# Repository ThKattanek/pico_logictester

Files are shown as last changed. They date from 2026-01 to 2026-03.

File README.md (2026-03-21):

# 🔌 Pico Logic Tester

  

> **Ein portabler 16-Kanal Logic Tester basierend auf dem Raspberry Pi Pico**

Der Pico Logic Tester ist ein handliches Debugging-Tool für Hardware-Entwickler. Er ersetzt die klassischen Test-LEDs und zeigt bis zu 16 digitale Signale gleichzeitig in Echtzeit auf einem farbigen TFT-Display an.

<div style="text-align: left; margin-left: 0; padding-left: 0;">
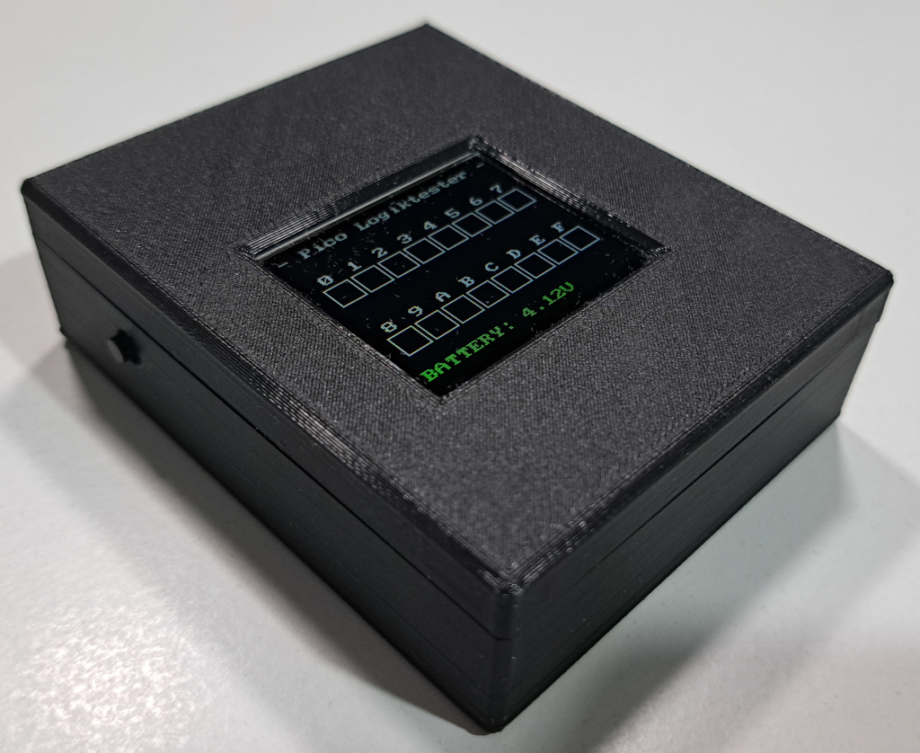
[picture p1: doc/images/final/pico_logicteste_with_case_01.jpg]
  
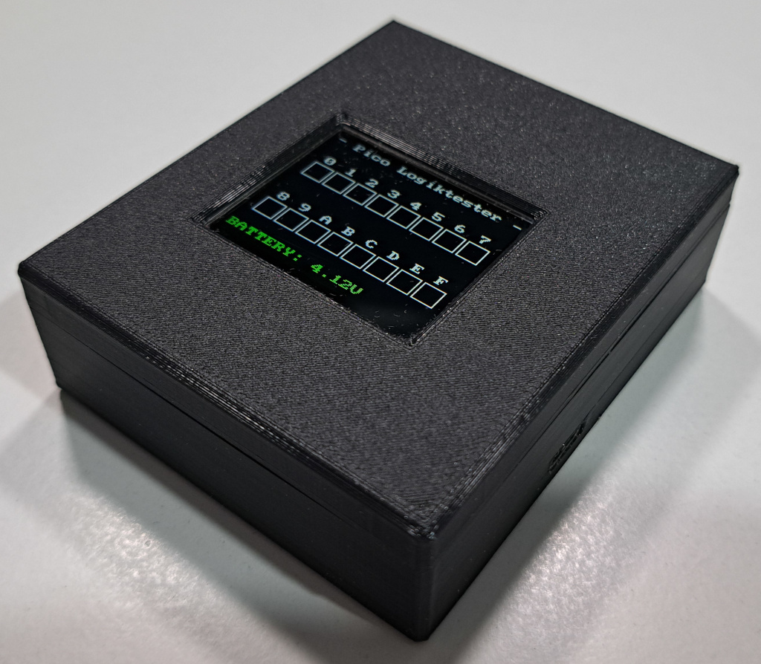
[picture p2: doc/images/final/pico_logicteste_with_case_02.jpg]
  
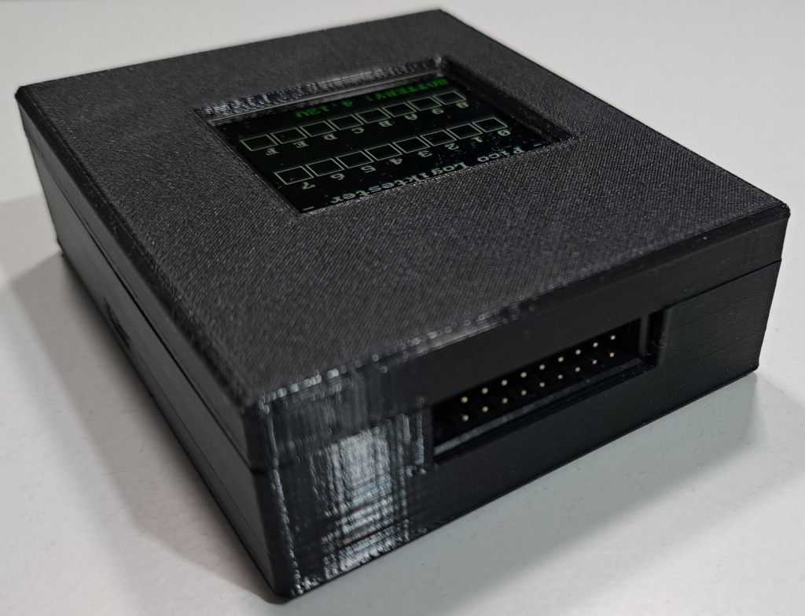
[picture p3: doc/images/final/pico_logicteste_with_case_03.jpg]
  
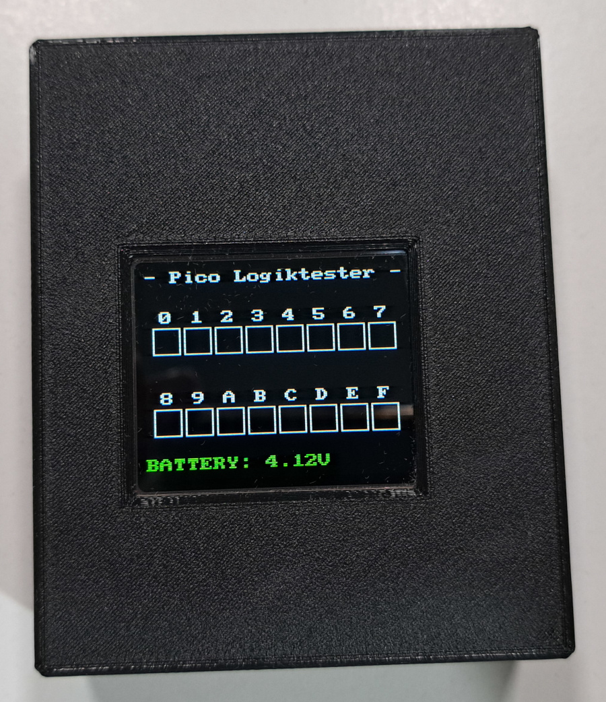
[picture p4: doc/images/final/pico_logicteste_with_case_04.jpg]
  
</div>

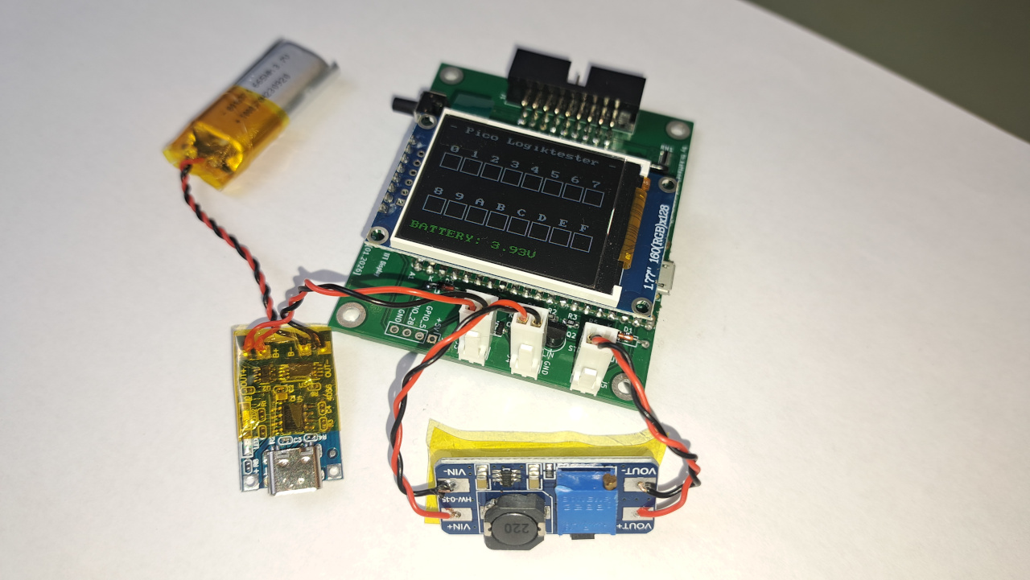
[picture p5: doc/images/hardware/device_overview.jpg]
Pico Logic Tester Overview

*Der Pico Logic Tester in Aktion*

---

## Key Features

| Feature | Beschreibung |
|---|---|
| **16 Logic Inputs** | GPIO 6-17, 20-22, 26-27 |
| **1,77" TFT Display** | 128x160 Pixel, 16-bit Farbe |
| **Akku-betrieben** | Li-Ion mit USB-C Laden |
| **3.3V & 5V tolerant** | Sichere Eingangsstufe |
| **Echtzeit-Anzeige** | <10ms Reaktionszeit |
| **Open Source** | Hardware & Software frei verfügbar |

---

## 🛠️ Technische Daten

### Hardware Specs
| Komponente | Spezifikation |
|---|---|
| **MCU** | Raspberry Pi Pico (RP2040/RP2350) |
| **Display** | ST7735S, 128×160, SPI |
| **Eingänge** | 16× Digital, 0-5V |
| **Stromversorgung** | 3.7V Li-Ion Akku |
| **Gehäuse** | 120×80×25mm (3D-druckbar) |
| **Gewicht** | ~150g |

### Performance
- **Scan-Rate:** 200Hz (5ms pro Zyklus)
- **Logic Levels:** LOW <0.8V, HIGH >2.5V 
- **Akkulaufzeit:** ~8-12 Stunden aktiv
- **Display-Update:** Nur bei Änderungen (optimiert)

---

## 🚀 Quick Start

### 1. Hardware Setup
```
1. Akku über USB-C laden (grüne LED = voll)
2. Logic Tester einschalten (kurzer Power-Button Druck)
3. GND-Referenz mit Testobjekt verbinden
4. Testleitungen an Eingänge 0-15 anschließen
```

### 2. Display Interpretation
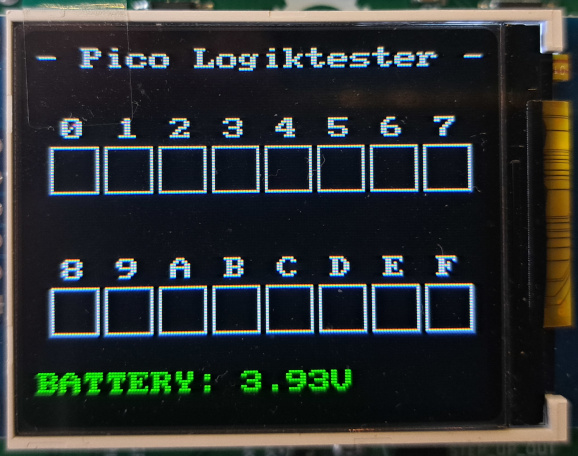
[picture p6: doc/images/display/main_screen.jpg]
Display Layout


| Anzeige | Bedeutung |
|---|---|
| **Grüne Box** | Logic HIGH (>2.5V) |
| **Schwarze Box** | Logic LOW (<0.8V) |
| **Grün/Gelb/Rot** | Batteriestatus |

### 3. Ein/Ausschalten
- **EIN:** Kurzer Tastendruck (<1s)
- **AUS:** Langer Tastendruck (>2s)
- **Auto-OFF:** Bei kritischem Batteriestand

---

## 📁 Repository Struktur

```
pico_logictester/
├── README.md                    # Diese Datei
├── LICENSE                      # GPL v2 Lizenz
├── firmware/                    # Pico C++ Firmware
│   ├── src/main.cpp               # Hauptprogramm
│   ├── CMakeLists.txt             # Build Config
│   └── include/displaylib_16/     # Display Treiber
├── hardware/                    # KiCad PCB Design
│   ├── pico_logictester.kicad_*   # Schaltplan & Layout
│   ├── gerber/                    # Produktionsdaten
│   └── bom/                       # Interaktive Stückliste
└── doc/                         # Dokumentation
    ├── pico_logictester_dokumentation.md  # Vollständige Doku
    ├── pico_logictester_dokumentation.pdf # PDF Version
    └── images/                     # Bilder & Diagramme
```

---

## 🔨 Build & Flash

### Voraussetzungen
- **Pico SDK** (v2.2.0+)
- **CMake** (v3.13+) 
- **ARM GCC Toolchain**

### Kompilierung
```bash
cd firmware
mkdir build && cd build
cmake ..
make -j4
```

### Programmierung
```bash
# UF2 auf Pico kopieren (BOOTSEL Mode)
cp pico_logictester.uf2 /media/<user>/RPI-RP2/

# Oder mit picotool
picotool load pico_logictester.uf2
```

---

## 📸 Screenshots

<table>
<tr>
<td align="center">
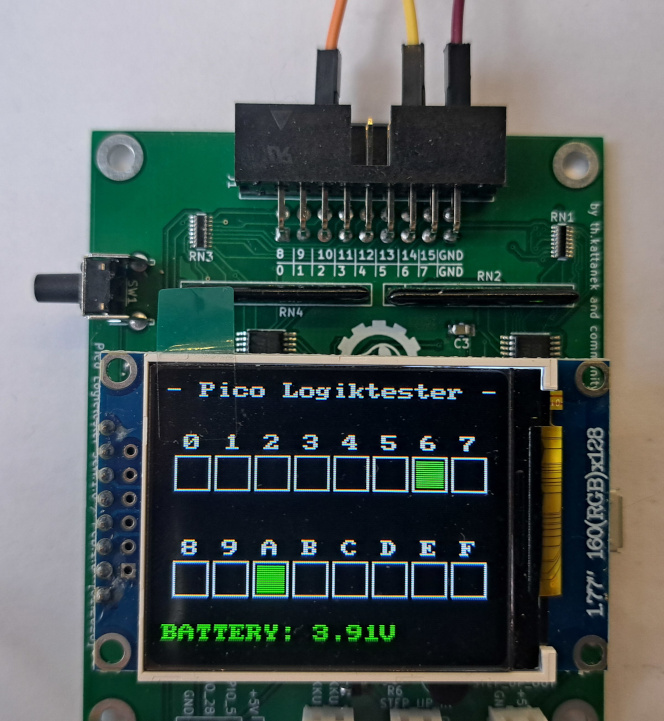
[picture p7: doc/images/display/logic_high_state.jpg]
<br>
<b>Logic HIGH Signale</b>
</td>
<td align="center">
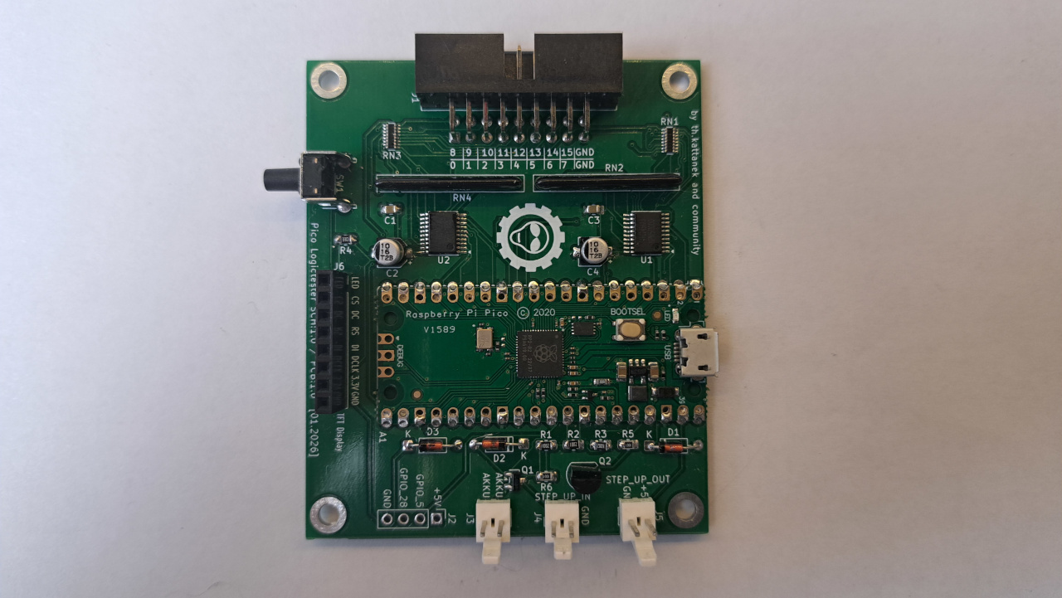
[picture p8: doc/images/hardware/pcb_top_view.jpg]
<br>
<b>PCB Design</b>
</td>
</tr>
</table>

---

## 📚 Dokumentation

| Dokument | Beschreibung | Format |
|---|---|---|
| 📋 **[Vollständige Dokumentation](doc/pico_logictester_dokumentation.md)** | Detaillierte Hardware/Software Beschreibung | Markdown |
| 📄 **[PDF Version](doc/pico_logictester_dokumentation.pdf)** | Druckbare Dokumentation | PDF |
| 🔧 **[Hardware BOM](hardware/bom/pico_logictester_pcb_1.0_ibom.html)** | Interaktive Stückliste | HTML |

### Was Sie in der Dokumentation finden:
- **Hardware-Design:** Schaltplan, PCB-Layout, Stückliste
- **Software-Architektur:** C++ Code-Struktur, Performance-Optimierungen  
- **Benutzerhandbuch:** Bedienung, Fehlerbehebung, Kalibrierung
- **Fertigung:** PCB-Produktion, 3D-Druck Gehäuse
- **Entwicklung:** Build-System, Debugging, Erweiterungen

---

## Beitragen

Contributions sind willkommen!

### Wie Sie helfen können:
- **Bug Reports:** Issues über GitHub melden
- **Feature Requests:** Neue Ideen vorschlagen  
- **Code:** Pull Requests für Verbesserungen
- **Dokumentation:** Rechtschreibfehler, Übersetzungen
- **Testing:** Hardware-Tests, Kompatibilitätsprüfung

### Development Workflow:
```bash
1. Fork das Repository
2. Feature Branch erstellen (`git checkout -b feature/amazing-feature`)
3. Änderungen committen (`git commit -m 'Add amazing feature'`)
4. Branch pushen (`git push origin feature/amazing-feature`)
5. Pull Request öffnen
```

---

## 📜 Lizenz

Dieses Projekt steht unter der **GNU General Public License v2.0**.

- ✅ **Kommerzieller Einsatz erlaubt**
- ✅ **Modifikation erlaubt** 
- ✅ **Distribution erlaubt**
- ❗ **Quellcode muss verfügbar sein**
- ❗ **Gleiche Lizenz für Ableitungen**

Siehe [LICENSE](LICENSE) für Details.

---

## Show your Support

Wenn Ihnen dieses Projekt gefällt:
- **Star** das Repository
- **Fork** für eigene Experimente  
- **Teilen** mit anderen Hardware-Hackern
- **Feedback** über Issues

---

## 📞 Kontakt & Support

| Kanal | Link | Beschreibung |
|---|---|---|
| 👤 **Autor** | Thorsten Kattanek | Hardware & Software Development |
| 📧 **E-Mail** | thorsten@kattanek.de | Direkte Fragen & Support |
| 🐙 **GitHub** | [ThKattanek/pico_logictester](https://github.com/ThKattanek/pico_logictester) | Source Code & Issues |
| 🐛 **Bug Reports** | [GitHub Issues](https://github.com/ThKattanek/pico_logictester/issues) | Bugs & Feature Requests |

---

<div align="center">

**Made with ❤️ for Hardware Debugging**

*Happy Coding!*

</div>

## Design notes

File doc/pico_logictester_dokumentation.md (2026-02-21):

# Pico Logic Tester - Projektdokumentation

**Version:** 1.0  
**Datum:**   21. Februar 2026  
**Autor:**   Thorsten Kattanek  

---

## 1. Projektübersicht

### 1.1 Beschreibung
Der Pico Logic Tester ist ein tragbares Messgerät zur Überwachung digitaler Signale, basierend auf dem Raspberry Pi Pico Mikrocontroller. Das Gerät kann bis zu 16 Logikeingänge gleichzeitig überwachen und den Zustand (HIGH/LOW) in Echtzeit auf einem farbigen TFT-Display anzeigen. Die Eingänge sind 3.3V und 5V Tolerant. Es ersetzt kein Logic Analyzer, vielmehr die LED's zum Debuggen von Hardware Schaltungen.

### 1.2 Hauptmerkmale
- **16 Logikeingänge** (GPIO 6-17, 20-22, 26-27)
- **1,77" ST7735 TFT-Display** (128x160 Pixel)
- **Batterieüberwachung** mit Spannungsanzeige
- **Power-Management** mit Ein-/Ausschaltfunktion
- **Portable Bauweise** mit integrierter Stromversorgung
- **Echtzeit-Anzeige** mit optimierter Performance

### 1.3 Technische Spezifikationen
- **Mikrocontroller:** Raspberry Pi Pico (RP2040) oder Pico2 (RP2350)
- **Betriebsspannung:** 3,3V - 4,2V (Li-Ion Akku)
- **Eingangsspannung:** 0V - 5V (tolerant)
- **Display:** ST7735S, 128x160 Pixel, 16-bit Farbtiefe
- **Kommunikation:** SPI (Display), GPIO (Logikeingänge)
- **Stromverbrauch:** ~50mA (aktiv), <1µA (Standby)

---

## 2. Hardware-Design

Gesamtansicht des Pico Logictester
*Abbildung 1: Gesamtansicht des Pico Logictester "noch" ohne Gehäuse*

### 2.1 Schaltungsaufbau
Die Hardware basiert auf einem zweischichtigen PCB-Design mit folgenden Hauptkomponenten:

PCB Oberseite
*Abbildung 2: PCB Oberseite mit bestückten Komponenten*

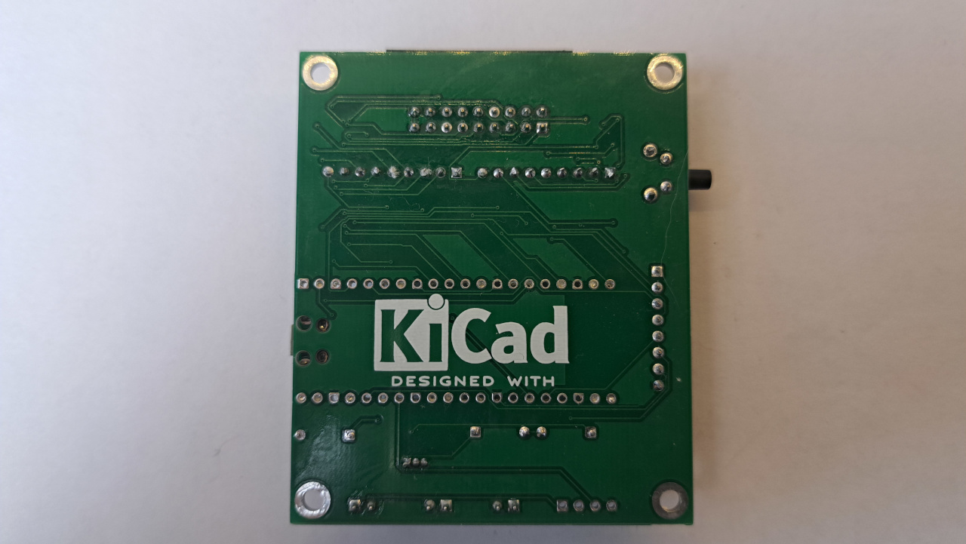
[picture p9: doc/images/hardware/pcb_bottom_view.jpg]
PCB Unterseite

*Abbildung 3: PCB Unterseite mit Leiterbahnen*

#### 2.1.1 Mikrocontroller-Sektion
- **RP2040 oder RP2350** als zentrale Verarbeitungseinheit (auf dem Pico1 oder Pico2 Board)
- **Externe Oszillatorbeschaltung** für stabile Taktversorgung (auf dem Pico1 oder 2 Board)
- **Keine Übertaktung** für einen sicheren und stabilen Betrieb
- **Power-Management-Schaltung** mit PNP-Transistor und MOSFET
- **Das Raspberry Pi Pico Board** wird direkt auf die Platine gelötet

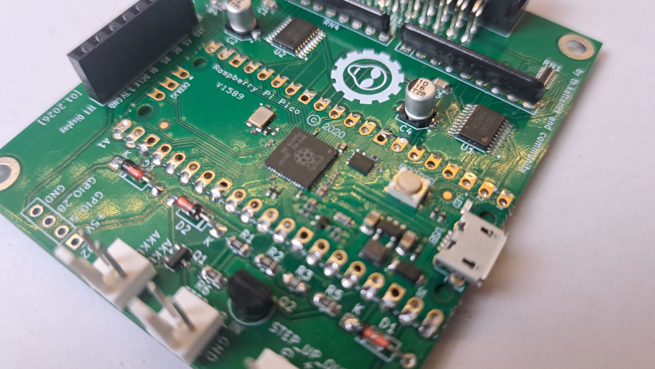
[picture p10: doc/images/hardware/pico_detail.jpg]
Pico Mikrocontroller Detail

*Abbildung 4: Detailansicht der Pico-Mikrocontroller Sektion*

#### 2.1.2 Eingangsstufe
- **16 Logikeingänge** mit Schutzwiderständen
- **74HC245** als schneller und zuverlässiger Pegelwandler
- **Pull-Down Widerstände** für definierte Pegel

#### 2.1.3 Display-Interface
- **ST7735S TFT-Controller** über SPI-Interface
- **Dedicated GPIO-Pins** für CS, DC, RST, SDIN und SDCLCK

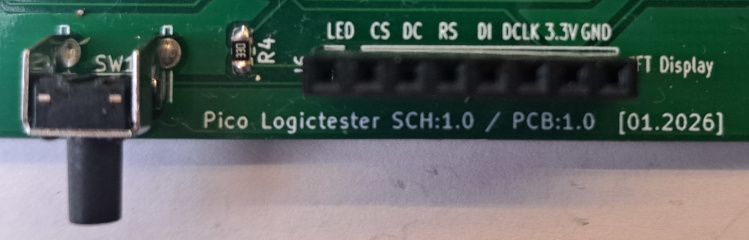
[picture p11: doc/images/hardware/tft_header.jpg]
Pinout TFT Header

*Abbildung 5: Pin Belegung des TFT Anschluss*

#### 2.1.4 Stromversorgung
- **Li-Ion Akkuanschluss** (3,7V nominal)
- **Laderegler-Modul (18650 Lithium Battery Charger)** mit USB-C Anschluss
- **StepUp Wandler Modul MT3608** erzeugt Stabile 5V für das ganze System
- **Spannungsüberwachung** über ADC-Eingang
- **Power-Switch mit Latching** über Taster

### 2.2 Pin-Belegung

#### 2.2.1 Display-Pins (SPI0)
```
TFT_CS_PIN    = GPIO 2   (Chip Select)
TFT_DC_PIN    = GPIO 3   (Data/Command)
TFT_RST_PIN   = GPIO 4   (Reset)
TFT_SDIN_PIN  = GPIO 19  (MOSI)
TFT_SCLK_PIN  = GPIO 18  (Serial Clock)
```

#### 2.2.2 Power-Management
```
SYSTEM_POWER_PIN = GPIO 0  (Power Control)
POWER_BUTTON_PIN = GPIO 1  (Power Button Input)
BATTERY_ADC_PIN  = GPIO 27 (Battery Voltage Monitoring)
```

#### 2.2.3 Debug-Interface
```
DEBUG_LED_PIN = GPIO 25   (Onboard LED für Status-Anzeige)
```

#### 2.2.3 Logikeingänge
```
LOGIC_PIN_0  = GPIO 6    LOGIC_PIN_8  = GPIO 14
LOGIC_PIN_1  = GPIO 7    LOGIC_PIN_9  = GPIO 15
LOGIC_PIN_2  = GPIO 8    LOGIC_PIN_10 = GPIO 16
LOGIC_PIN_3  = GPIO 9    LOGIC_PIN_11 = GPIO 17
LOGIC_PIN_4  = GPIO 10   LOGIC_PIN_12 = GPIO 20
LOGIC_PIN_5  = GPIO 11   LOGIC_PIN_13 = GPIO 21
LOGIC_PIN_6  = GPIO 12   LOGIC_PIN_14 = GPIO 22
LOGIC_PIN_7  = GPIO 13   LOGIC_PIN_15 = GPIO 26
```

---

## 3. Software-Architektur

### 3.1 Systemarchitektur
Die Firmware ist in C++ geschrieben und verwendet das Pico SDK. Die Software folgt einer ereignisgesteuerten Architektur mit optimierter Performance für Echtzeit-Anwendungen.

### 3.2 Hauptkomponenten

#### 3.2.1 Power Management System
```cpp
// Funktionen:
- InitPowerManagement()      // Initialisierung der Power-Kontrolle
- CheckPowerButton()         // Überwachung des Power-Buttons
- PowerOff()                 // Sicheres Herunterfahren
```

**Features:**
- Interrupt-gesteuerte Tastererkennung
- 2-Sekunden-Timeout für sicheres Ausschalten
- Automatische Abschaltung bei kritischer Batteriespannung

#### 3.2.2 Battery Monitoring System
```cpp
// Funktionen:
- InitBatteryMonitoring()    // ADC-Initialisierung
- ReadBatteryVoltage()       // Spannungsmessung
- UpdateBatteryMovingAverage() // Gleitender Mittelwert
- DisplayBatteryStatus()     // Anzeige der Batteriespannung
```

**Features:**
- 12-bit ADC mit 3,3V Referenz
- 50-Werte gleitender Mittelwert für stabile Messung
- Farbkodierte Warnanzeige (Grün/Gelb/Rot)
- Automatische Abschaltung bei <3,5V

#### 3.2.3 Logic Input System
```cpp
// Funktionen:
- InitLogicPinsAsInput()     // GPIO-Initialisierung
- ReadAllLogicPins()         // Bulk-GPIO-Read
- UpdateLogicDisplay()       // Selektive Display-Updates
```

**Features:**
- Optimierte Bulk-GPIO-Operationen
- Änderungsbasierte Display-Updates
- Sub-10ms Reaktionszeit
- 16MHz SPI für flüssige Anzeige

#### 3.2.4 Display System
Das Display-System basiert auf der `displaylib_16` Bibliothek mit ST7735-Treiber.

**Features:**
- Hardware-SPI mit 16MHz Taktrate
- 16-bit Farbtiefte (65.536 Farben)
- Optimierte Zeichenfunktionen
- Rotationsunterstützung (0°, 90°, 180°, 270°)

#### 3.2.5 Debug-System
```cpp
// Debug-LED Funktionen:
- LED_PIN = GPIO 25          // Onboard-LED des Pico
- gpio_put(LED_PIN, 1)       // LED einschalten bei Startup
- Visueller Indikator für Systemstart
- Debugging-Unterstützung bei Entwicklung
```

**Features:**
- Automatisches LED-Signal beim Systemstart
- Status-Anzeige für Hardware-Debugging
- Einfache Erweiterung für weitere Debug-Signale

### 3.3 Performance-Optimierungen

#### 3.3.1 Echzeit-Verhalten
- **Hauptschleife:** 5ms Zykluszeit
- **GPIO-Read:** Bulk-Operation in <1µs
- **Display-Update:** Nur bei Änderungen
- **Batteriemessung:** 100ms Intervall

#### 3.3.2 Memory Management
- **Stack-optimierte Variablen**
- **Konstante Arrays im Flash**
- **Minimale Heap-Nutzung**
- **Optimierte Puffergröße**

---

## 4. Benutzerhandbuch

### 4.1 Inbetriebnahme

#### 4.1.1 Erste Verwendung
1. **Akku laden:** USB-C Kabel anschließen bis LED grün leuchtet
2. **Einschalten:** Power-Taste kurz drücken
3. **Display-Check:** Anzeige sollte "Pico Logiktester" zeigen
4. **Funktionstest:** Testspannungen an Eingänge anlegen

#### 4.1.2 Bedienung
- **Einschalten:** Kurzer Tastendruck (<1s)
- **Ausschalten:** Langer Tastendruck (>2s)
- **Automatische Abschaltung:** Bei kritischer Batteriespannung

### 4.2 Display-Anzeige

Hauptbildschirm
*Abbildung 6: Hauptbildschirm mit allen 16 Logikeingängen*

#### 4.2.1 Bildschirmaufteilung
```
+---------------------------+
|   - Pico Logiktester -    |  <- Header
+---------------------------+
|  0  1  2  3  4  5  6  7   |  <- Eingänge 0-7
| [_][_][_][_][_][_][_][_]  |
|                           |
|  8  9  A  B  C  D  E  F   |  <- Eingänge 8-15 (hex)
| [_][_][_][_][_][_][_][_]  |
+---------------------------+
| BATTERY: 4.05V            |  <- Batterie Anzeige
+---------------------------+
```

#### 4.2.2 Statusanzeige
- **Grüne Box:** Logik HIGH (>2,5V)
- **Schwarze Box:** Logik LOW (<0,8V)
- **Batterieanzeige:**
  - Grün: >3,7V (gut)
  - Gelb: 3,5V-3,7V (niedrig)
  - Rot: <3,5V (kritisch) (system wird automatisch runter gefahren)

Logic HIGH Anzeige
*Abbildung 7: Display mit mehreren HIGH-Signalen (grüne Boxen)*

### 4.3 Messverfahren

#### 4.3.1 Digitale Signale
- **Eingangsspannung:** 0V - 5V
- **Schaltschwellen:**
  - LOW: <0,8V
  - HIGH: >2,5V
- **Maximale Frequenz:** ~50Hz (begrenzt durch Display)

#### 4.3.2 Anschluss
1. **GND-Verbindung** zwischen Testobjekt und Logic Tester herstellen
2. **Messleitungen** an zu überwachende Signale anschließen  
3. **Eingangsnummer beachten** (0-15, entspricht GPIO-Mapping)

---

## 5. Entwicklung und Build

### 5.1 Build-System

#### 5.1.1 Voraussetzungen
```bash
# Pico SDK Installation
sudo apt install cmake gcc-arm-none-eabi libnewlib-arm-none-eabi \
                 build-essential libstdc++-arm-none-eabi-newlib

# Pico SDK (Version 2.2.0)
git clone https://github.com/raspberrypi/pico-sdk.git
export PICO_SDK_PATH=/path/to/pico-sdk
```

#### 5.1.2 Kompilierung
```bash
cd firmware
mkdir build && cd build
cmake ..
make -j4
```

#### 5.1.3 Programmierung
```bash
# UF2-Datei auf Pico kopieren (Bootsel-Modus)
cp pico_logictester.uf2 /media/<user>/RPI-RP2/

# Oder mit picotool
picotool load pico_logictester.uf2
```

### 5.2 Entwicklungsumgebung

#### 5.2.1 Empfohlene IDE
- **VS Code** mit Pico Extension

#### 5.2.2 Debugging
```bash
# SWD-Debugging mit Pico Debug Probe
openocd -f interface/cmsis-dap.cfg -f target/rp2040.cfg
arm-none-eabi-gdb build/pico_logictester.elf
```

### 5.3 Code-Struktur

#### 5.3.1 Verzeichnisstruktur
```
firmware/
├── CMakeLists.txt
├── src/
│   ├── main.cpp                 # Hauptprogramm
│   └── displaylib_16/           # Display-Bibliothek
│       ├── st7735.cpp           # ST7735 Treiber
│       ├── displaylib_16_*.cpp  # Grafik-Funktionen
│       └── ...
├── include/
│   └── displaylib_16/           # Header-Dateien
└── build/                       # Build-Artefakte
```

#### 5.3.2 Abhängigkeiten
```cmake
# CMakeLists.txt Ziele
target_link_libraries(pico_logictester
    pico_displaylib_16    # Eigene Display-Bibliothek
    hardware_spi          # SPI-Hardware
    hardware_adc          # ADC-Hardware  
    pico_stdlib           # Pico Standard-Bibliothek
)
```

---

## 6. Hardware-Fertigung

### 6.1 PCB-Spezifikationen

#### 6.1.1 Platinen-Parameter
- **Schichtanzahl:** 2 Layer
- **Platinen-Dicke:** 1,6mm
- **Kupfer-Dicke:** 35µm (1oz)
- **Via-Größe:** min 0,3mm Bohrdurchmesser
- **Leiterbahnbreite:** min. 0,2mm
- **Oberflächenfinish:** Bleifreies HASL

#### 6.1.2 Bestückung
- **SMD-Komponenten:** 0805 und 1206
- **Durchkontaktierte Bauteile:** THT-Stecker
- **Kritische Toleranzen:** ±5% (Widerstände), ±10% (Kondensatoren)

### 6.2 Stückliste (BOM)

Siehe unter hardware/bom, dort gibt es eine Interaktive Stückliste als HTML File. 

### 6.3 Gehäuse

#### 6.3.1 Mechanische Abmessungen
- **Außenmaße:** 120mm x 80mm x 25mm
- **Display-Ausschnitt:** 30mm x 26mm
- **Taster-Bohrung:** Ø6mm
- **Anschluss-Raster:** 2,54mm (16-pol Stiftleiste)

#### 6.3.2 Material-Empfehlungen
- **Gehäuse:** ABS oder PETG (3D-Druck)
- **Display-Schutz:** Acrylglas 2mm
- **Dichtungen:** Silikonprofil für IP54

---

## 7. Fehlerbehebung

### 7.1 Häufige Probleme

#### 7.1.1 Display bleibt schwarz
**Symptome:** Kein Bild nach dem Einschalten
**Ursachen:**
- Unterbrochene SPI-Verbindung
- Defekte Display-Spannungsversorgung
- Falsche Display-Initialisierung

**Lösungsansätze:**
```cpp
// Debug-Code für Display-Test
tft_display.fillScreen(ST7735_TFT::C_RED);  // Test mit rotem Bildschirm
```

#### 7.1.2 Eingänge reagieren nicht
**Symptome:** Keine Änderung der Logic-Anzeige
**Ursachen:**
- GPIO-Pins nicht korrekt initialisiert
- Hardwarefehler auf Eingangsstufe
- Software-Bug in ReadAllLogicPins()

**Lösungsansätze:**
```cpp
// Debug einzelner GPIO-Pin
printf("GPIO %d: %d\n", LOGIC_PIN_0, gpio_get(LOGIC_PIN_0));
```

#### 7.1.3 Batterie-Anzeige falsch
**Symptome:** Unrealistische Spannungswerte
**Ursachen:**
- ADC-Referenzspannung falsch
- Spannungsteiler-Verhältnis inkorrekt
- Schlechte ADC-Kalibrierung

**Lösungsansätze:**
```cpp
// ADC-Rohwerte prüfen
uint16_t raw = adc_read();
printf("ADC raw: %d\n", raw);
```

### 7.2 Debug-Ausgaben

#### 7.2.1 UART-Debugging
```cpp
// main.cpp - Debug-Ausgaben aktivieren
stdio_init_all();
pico_enable_stdio_uart(${PROJECT_NAME} 1);

// Verwenden in Code:
printf("Battery: %.2fV, Logic: 0x%04X\n", battery_voltage, logic_state);
```

#### 7.2.2 LED-Signaling
```cpp
// Status-LED für Fehlerdiagnose (bereits implementiert)
#define DEBUG_LED_PIN 25  // Onboard-LED des Pico
gpio_init(DEBUG_LED_PIN);
gpio_set_dir(DEBUG_LED_PIN, GPIO_OUT);
gpio_put(DEBUG_LED_PIN, 1); // LED an bei Startup

// Erweiterte Fehlercodes durch Blink-Sequenzen
void blink_error_code(int error_code) {
    for(int i = 0; i < error_code; i++) {
        gpio_put(DEBUG_LED_PIN, 1);
        sleep_ms(200);
        gpio_put(DEBUG_LED_PIN, 0);
        sleep_ms(200);
    }
}

// Status-Signale:
// - Dauerhaft AN: System erfolgreich gestartet
// - Blink-Codes: Verschiedene Fehlerzustände
```

---

## 8. Wartung und Pflege

### 8.1 Routinewartung

#### 8.1.1 Batteriepflege
- **Ladezyklen:** Nicht vollständig entladen lassen
- **Lagerung:** Bei 50% SOC lagern wenn unbenutzt
- **Lade-Temperatur:** 10°C - 45°C optimal
- **Austausch:** Nach ca. 500 Ladezyklen

#### 8.1.2 Reinigung
- **Display:** Mit Mikrofasertuch trocken reinigen
- **Gehäuse:** Mit feuchtem Tuch (destilliertes Wasser)
- **Anschlüsse:** Mit Kontaktspray behandeln
- **Lagerung:** In antistatischer Hülle

### 8.2 Kalibrierung

#### 8.2.1 Batteriespannung
```cpp
// Kalibrierung der ADC-Messung
const float ADC_CALIBRATION_FACTOR = 1.02f;  // Anpassung nach Messung
float voltage = adc_raw * ADC_CONVERSION_FACTOR * 
                VOLTAGE_DIVIDER_FACTOR * ADC_CALIBRATION_FACTOR;
```

#### 8.2.2 Eingangsschwellen
```cpp
// Logic-Level Kalibrierung  
const float LOGIC_LOW_THRESHOLD = 0.8f;   // Anpassbar
const float LOGIC_HIGH_THRESHOLD = 2.5f;  // Anpassbar
```

---

## 9. Anhang

### 9.1 Technische Referenzen

#### 9.1.1 Datenblätter
- [RP2040 Datasheet](https://datasheets.raspberrypi.org/rp2040/rp2040-datasheet.pdf)
- [ST7735 Controller](https://www.adafruit.com/datasheets/ST7735R_V0.2.pdf)
- [Pico SDK Documentation](https://raspberrypi.github.io/pico-sdk-doxygen/)

#### 9.1.2 Application Notes
- **AN001:** Power Management Best Practices
- **AN002:** EMV-Design für portable Geräte  
- **AN003:** Li-Ion Battery Safety

### 9.2 Lizenz und Copyright

#### 9.2.1 Software-Lizenz
```
GNU General Public License Version 2

Copyright (C) 2026 Thorsten Kattanek

This program is free software; you can redistribute it and/or modify
it under the terms of the GNU General Public License as published by
the Free Software Foundation; either version 2 of the License, or
(at your option) any later version.

This program is distributed in the hope that it will be useful,
but WITHOUT ANY WARRANTY; without even the implied warranty of
MERCHANTABILITY or FITNESS FOR A PARTICULAR PURPOSE.  See the
GNU General Public License for more details.

You should have received a copy of the GNU General Public License along
with this program; if not, write to the Free Software Foundation, Inc.,
51 Franklin Street, Fifth Floor, Boston, MA 02110-1301 USA.

Die vollständige Lizenz finden Sie in der Datei LICENSE im Repository.
```

#### 9.2.2 Hardware-Lizenz
Das Hardware-Design steht unter Creative Commons Attribution-ShareAlike 4.0 International License.

**Autor:** Thorsten Kattanek  
**E-Mail:** mail@thorsten-kattanek.de  
**Repository:** https://github.com/ThKattanek/pico_logictester  
**Issues:** Bug-Reports und Feature-Requests über GitHub Issues

---

*Dokumentation erstellt am 21. Februar 2026*  
*Version 1.0*

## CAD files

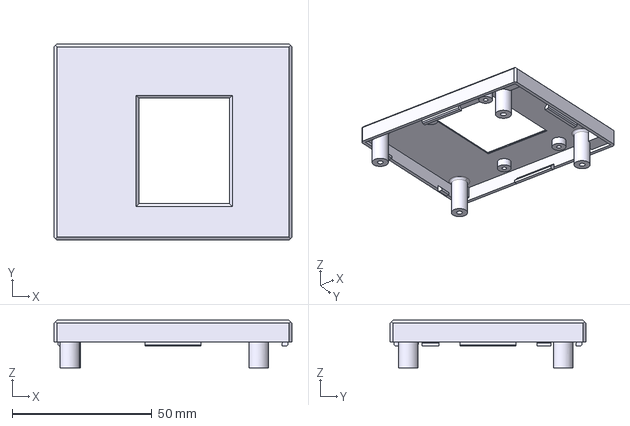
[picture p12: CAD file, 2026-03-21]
case/freecad/pico_logictester_case-top_case.step
85.0 x 70.0 x 17.0 mm

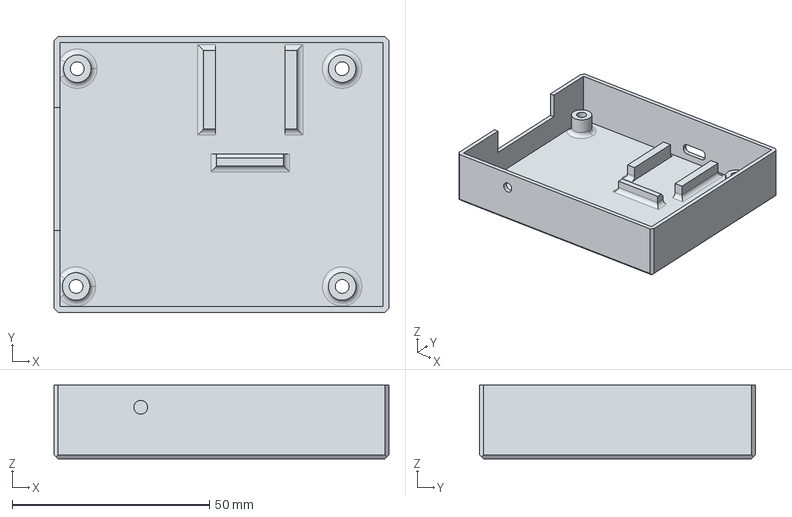
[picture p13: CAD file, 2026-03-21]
case/freecad/pico_logictester_case-bottom_case.step
85.0 x 70.0 x 18.7 mm

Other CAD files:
case/freecad/pico_logictester_case.FCStd

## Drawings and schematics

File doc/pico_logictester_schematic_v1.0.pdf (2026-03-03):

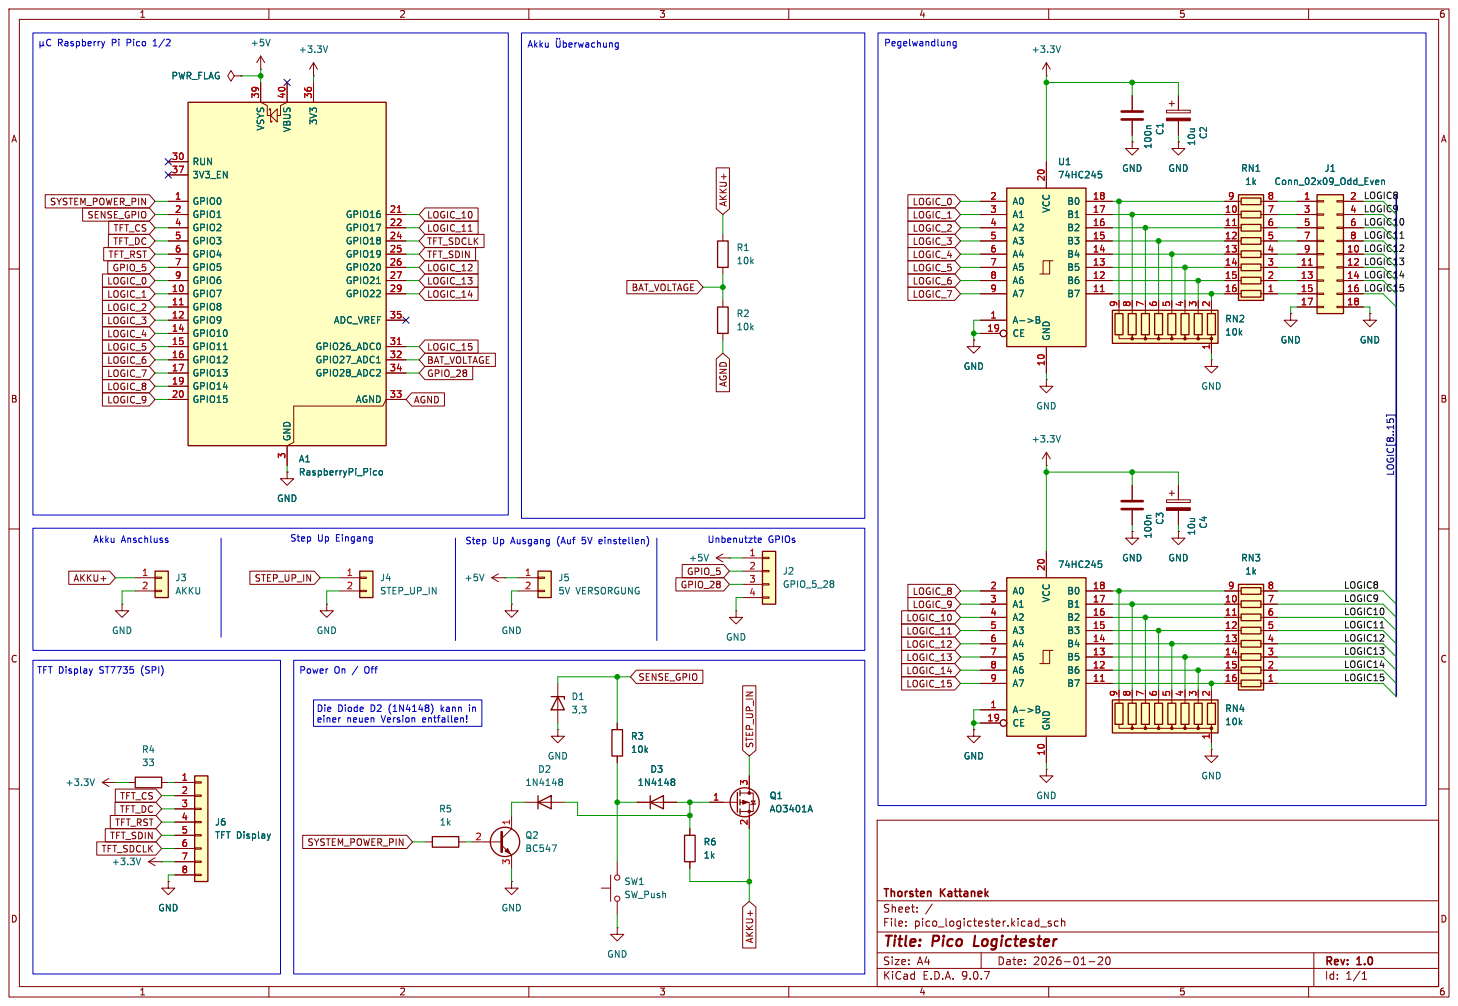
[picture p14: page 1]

LOGIC13 Step Up Ausgang (Auf 5V einstellen)

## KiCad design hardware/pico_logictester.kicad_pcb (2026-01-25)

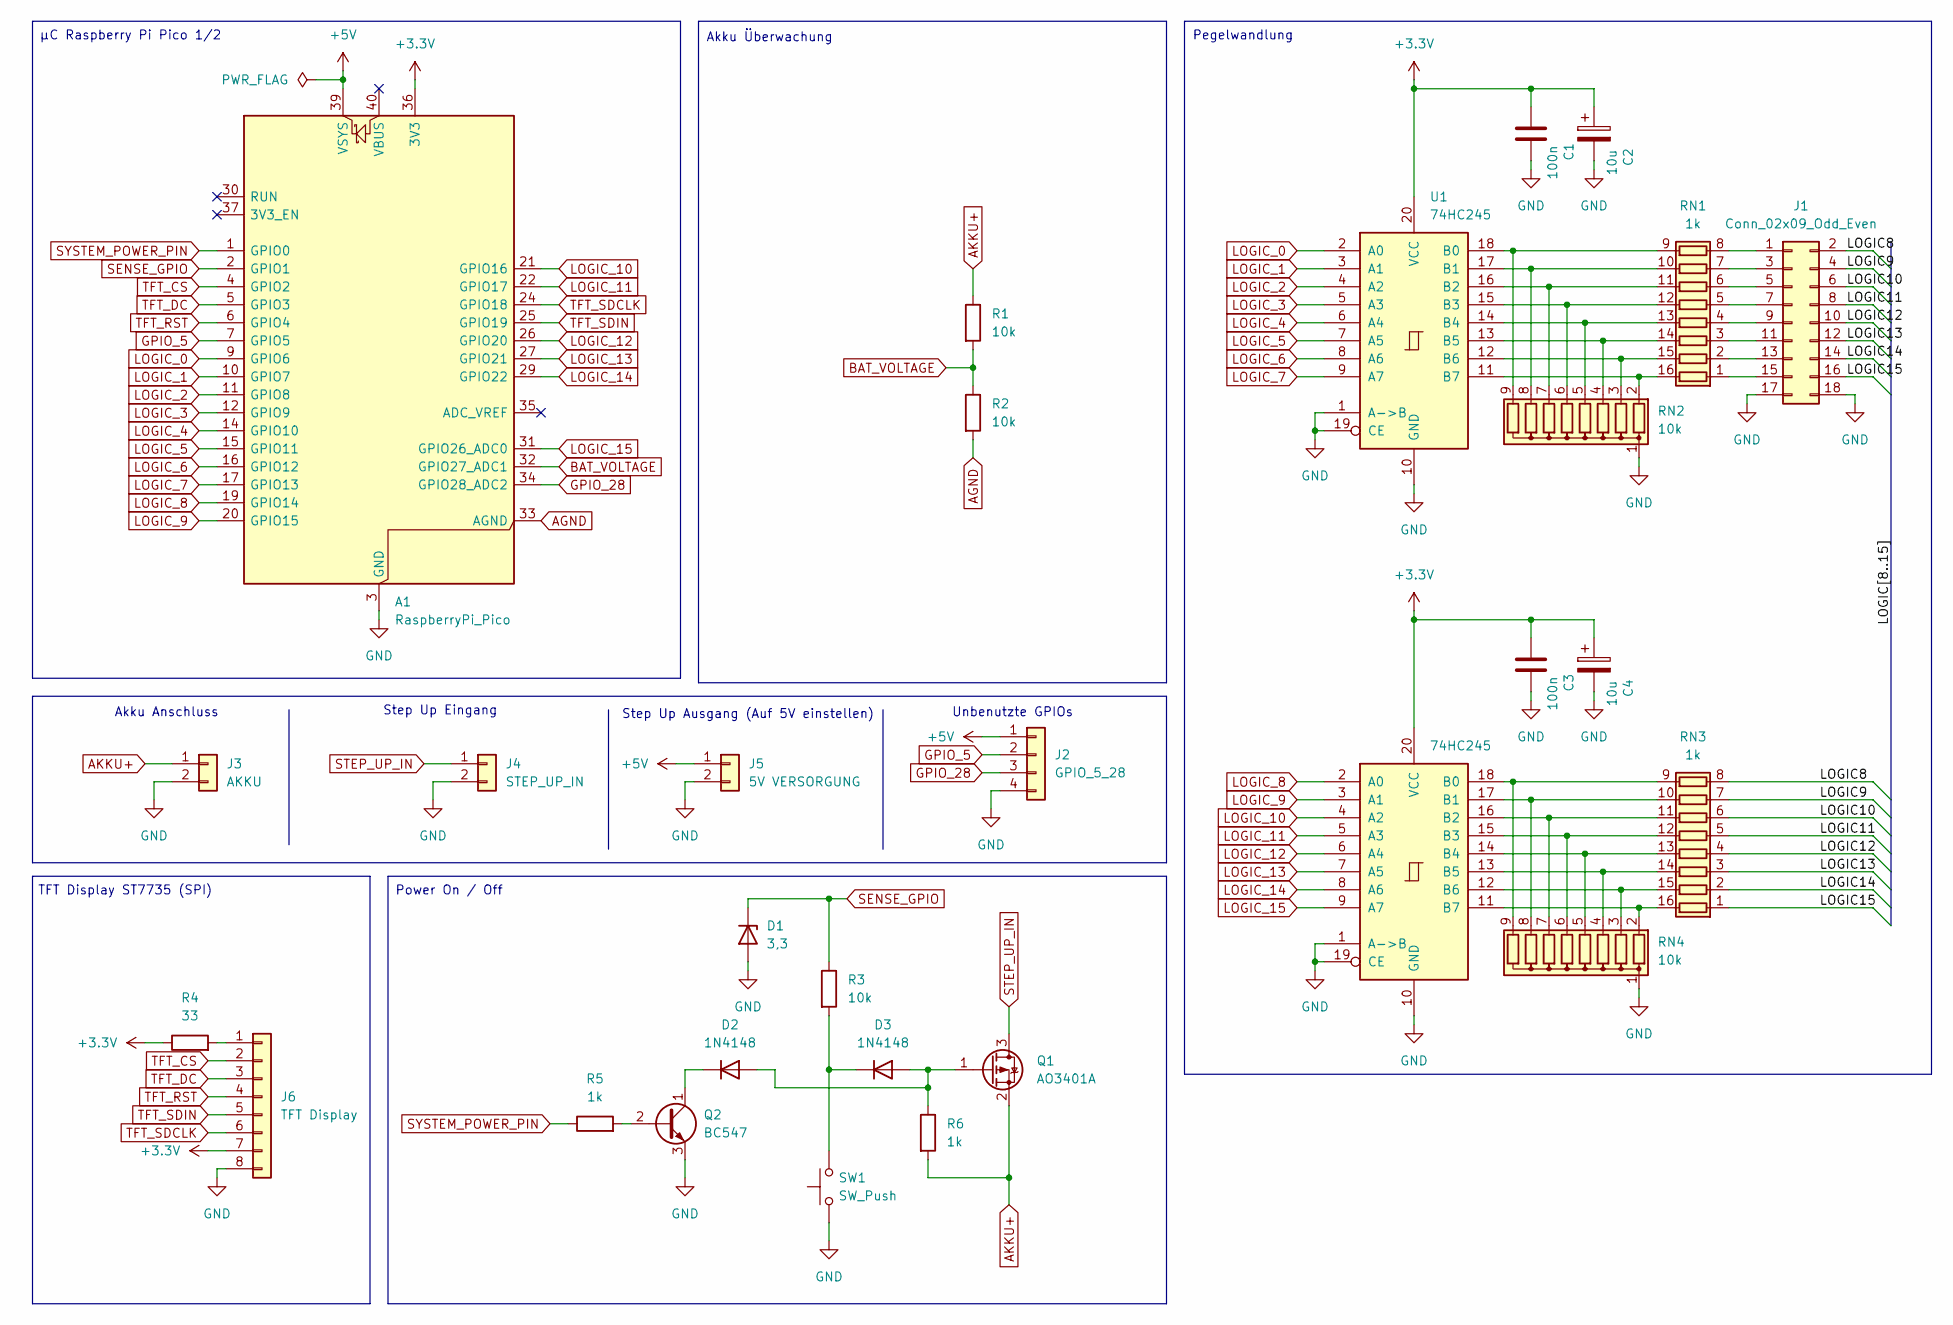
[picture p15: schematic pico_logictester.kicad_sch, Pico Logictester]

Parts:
A1: RaspberryPi_Pico; RaspberryPi_Pico_Common_Unspecified
C1, C3: 100n; C_0805_2012Metric_Pad1.18x1.45mm_HandSolder
C2, C4: 10u; CP_Elec_4x5.4
D1: 3,3; D_DO-35_SOD27_P7.62mm_Horizontal
D2, D3: 1N4148; D_DO-35_SOD27_P7.62mm_Horizontal
J1: Conn_02x09_Odd_Even; IDC-Header_2x09_P2.54mm_Horizontal
J2: GPIO_5_28; PinHeader_1x04_P2.54mm_Vertical
J3: AKKU; PinHeader_1x02_P2.54mm_Vertical
J4: STEP_UP_IN; PinHeader_1x02_P2.54mm_Vertical
J5: 5V VERSORGUNG; PinHeader_1x02_P2.54mm_Vertical
J6: TFT Display; PinSocket_1x08_P2.54mm_Vertical
Q1: AO3401A; SOT-23
Q2: BC547; TO-92_Inline
R1, R2, R3: 10k; R_0805_2012Metric_Pad1.20x1.40mm_HandSolder
R4: 33; R_0805_2012Metric_Pad1.20x1.40mm_HandSolder
R5, R6: 1k; R_0805_2012Metric_Pad1.20x1.40mm_HandSolder
RN1, RN3: 1k; R_Array_Convex_8x0602
RN2, RN4: 10k; R_Array_SIP9
SW1: SW_Push; SW_PUSH_6mm_H9.5mm
U1, U2: 74HC245; TSSOP-20_4.4x6.5mm_P0.65mm

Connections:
+3.3V: A1.36 (3V3), C1.1, C2.1, C3.1, C4.1, J6.7, R4.1, U1.20 (VCC), U2.20 (VCC)
+5V: A1.39 (VSYS), J2.1, J5.1
/LOGIC8: J1.2, RN3.8 (R8.1)
/LOGIC9: J1.4, RN3.7 (R7.1)
/LOGIC10: J1.6, RN3.6 (R6.1)
/LOGIC11: J1.8, RN3.5 (R5.1)
/LOGIC12: J1.10, RN3.4 (R4.1)
/LOGIC13: J1.12, RN3.3 (R3.1)
/LOGIC14: J1.14, RN3.2 (R2.1)
/LOGIC15: J1.16, RN3.1 (R1.1)
AGND: A1.33 (AGND), R2.2
AKKU+: J3.1, Q1.2 (S), R1.1, R6.2
BAT_VOLTAGE: A1.32 (GPIO27_ADC1), R1.2, R2.1
GND: A1.3 (GND), A1.8 (GND), A1.13 (GND), A1.18 (GND), A1.23 (GND), A1.28 (GND), A1.38 (GND), C1.2, C2.2, C3.2, C4.2, D1.2 (A), J1.17, J1.18, J2.4, J3.2, J4.2, J5.2, J6.8, Q2.3 (E), RN2.1 (common), RN4.1 (common), SW1.1, U1.1 (A->B), U1.10 (GND), U1.19 (CE), U2.1 (A->B), U2.10 (GND), U2.19 (CE)
GPIO_5: A1.7 (GPIO5), J2.2
GPIO_28: A1.34 (GPIO28_ADC2), J2.3
LOGIC_0: A1.9 (GPIO6), U1.2 (A0)
LOGIC_1: A1.10 (GPIO7), U1.3 (A1)
LOGIC_2: A1.11 (GPIO8), U1.4 (A2)
LOGIC_3: A1.12 (GPIO9), U1.5 (A3)
LOGIC_4: A1.14 (GPIO10), U1.6 (A4)
LOGIC_5: A1.15 (GPIO11), U1.7 (A5)
LOGIC_6: A1.16 (GPIO12), U1.8 (A6)
LOGIC_7: A1.17 (GPIO13), U1.9 (A7)
LOGIC_8: A1.19 (GPIO14), U2.2 (A0)
LOGIC_9: A1.20 (GPIO15), U2.3 (A1)
LOGIC_10: A1.21 (GPIO16), U2.4 (A2)
LOGIC_11: A1.22 (GPIO17), U2.5 (A3)
LOGIC_12: A1.26 (GPIO20), U2.6 (A4)
LOGIC_13: A1.27 (GPIO21), U2.7 (A5)
LOGIC_14: A1.29 (GPIO22), U2.8 (A6)
LOGIC_15: A1.31 (GPIO26_ADC0), U2.9 (A7)
unnamed: D2.2 (A), D3.2 (A), Q1.1 (G), R6.1
unnamed: D2.1 (K), Q2.1 (C)
unnamed: D3.1 (K), R3.2, SW1.2
unnamed: J1.1, RN1.8 (R8.1)
unnamed: J1.3, RN1.7 (R7.1)
unnamed: J1.5, RN1.6 (R6.1)
unnamed: J1.7, RN1.5 (R5.1)
unnamed: J1.9, RN1.4 (R4.1)
unnamed: J1.11, RN1.3 (R3.1)
unnamed: J1.13, RN1.2 (R2.1)
unnamed: J1.15, RN1.1 (R1.1)
unnamed: J6.1, R4.2
unnamed: Q2.2 (B), R5.2
unnamed: RN1.16 (R1.2), RN2.2 (R1), U1.11 (B7)
unnamed: RN1.15 (R2.2), RN2.3 (R2), U1.12 (B6)
unnamed: RN1.14 (R3.2), RN2.4 (R3), U1.13 (B5)
unnamed: RN1.13 (R4.2), RN2.5 (R4), U1.14 (B4)
unnamed: RN1.12 (R5.2), RN2.6 (R5), U1.15 (B3)
unnamed: RN1.11 (R6.2), RN2.7 (R6), U1.16 (B2)
unnamed: RN1.10 (R7.2), RN2.8 (R7), U1.17 (B1)
unnamed: RN1.9 (R8.2), RN2.9 (R8), U1.18 (B0)
unnamed: RN3.16 (R1.2), RN4.2 (R1), U2.11 (B7)
unnamed: RN3.15 (R2.2), RN4.3 (R2), U2.12 (B6)
unnamed: RN3.14 (R3.2), RN4.4 (R3), U2.13 (B5)
unnamed: RN3.13 (R4.2), RN4.5 (R4), U2.14 (B4)
unnamed: RN3.12 (R5.2), RN4.6 (R5), U2.15 (B3)
unnamed: RN3.11 (R6.2), RN4.7 (R6), U2.16 (B2)
unnamed: RN3.10 (R7.2), RN4.8 (R7), U2.17 (B1)
unnamed: RN3.9 (R8.2), RN4.9 (R8), U2.18 (B0)
SENSE_GPIO: A1.2 (GPIO1), D1.1 (K), R3.1
STEP_UP_IN: J4.1, Q1.3 (D)
SYSTEM_POWER_PIN: A1.1 (GPIO0), R5.1
TFT_CS: A1.4 (GPIO2), J6.2
TFT_DC: A1.5 (GPIO3), J6.3
TFT_RST: A1.6 (GPIO4), J6.4
TFT_SDCLK: A1.24 (GPIO18), J6.6
TFT_SDIN: A1.25 (GPIO19), J6.5

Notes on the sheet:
Pegelwandlung
Unbenutzte GPIOs
µC Raspberry Pi Pico 1/2
Step Up Ausgang (Auf 5V einstellen)
Step Up Eingang
TFT Display ST7735 (SPI)
Akku Anschluss
Akku Überwachung
Power On / Off

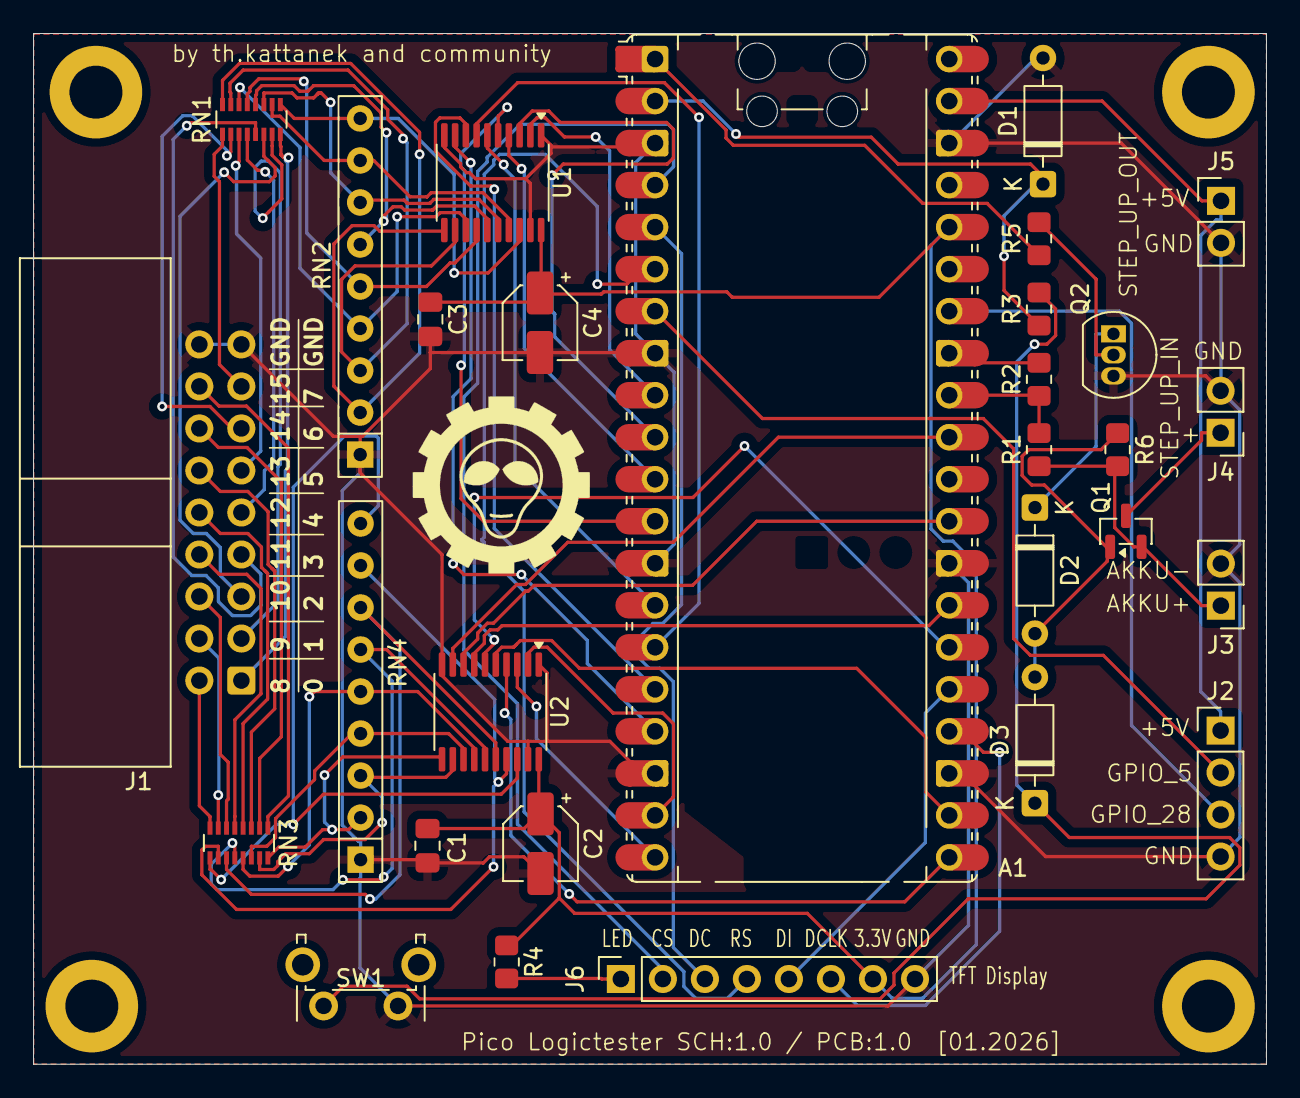
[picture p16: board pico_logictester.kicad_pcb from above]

Board: 2 copper layers, 74.5 x 62.3 mm, 33 parts (0 on the bottom side), 69 nets.

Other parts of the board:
REF1, REF2, REF3, REF4: MountingHole_3.2mm_M3_DIN965_Pad

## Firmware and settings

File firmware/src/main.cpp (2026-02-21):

#include <stdio.h>
#include "pico/stdlib.h"
#include "hardware/gpio.h"
#include "hardware/adc.h"
#include "displaylib_16/displaylib_16_Font.hpp"
#include "displaylib_16/st7735.hpp"

// Display GPIO and SPI configuration
// SPI0 
#define TFT_CS_PIN    2     // Chip Select pin
#define TFT_DC_PIN    3     // Data/Command pin
#define TFT_RST_PIN   4     // Reset pin
#define TFT_SDIN_PIN  19    // Master Out Slave In pin
#define TFT_SCLK_PIN   18   // Serial Clock pin   

#define TFT_WIDTH     128   // Display width in pixels
#define TFT_HEIGHT    160   // Display height in pixels

// Power management pins
#define SYSTEM_POWER_PIN 0    // Controls PNP transistor to keep system powered ()
#define POWER_BUTTON_PIN 1    // Power button input

// Battery monitoring
#define BATTERY_ADC_PIN 27    // ADC1 - Battery voltage measurement
#define BATTERY_ADC_CHANNEL 1 // ADC channel 1 (GPIO 27)

// Logic Input GPIO pins
#define LOGIC_PIN_0 6       // Logic Input Pin 0
#define LOGIC_PIN_1 7       // Logic Input Pin 1
#define LOGIC_PIN_2 8       // Logic Input Pin 2
#define LOGIC_PIN_3 9       // Logic Input Pin 3
#define LOGIC_PIN_4 10      // Logic Input Pin 4
#define LOGIC_PIN_5 11      // Logic Input Pin 5
#define LOGIC_PIN_6 12      // Logic Input Pin 6
#define LOGIC_PIN_7 13      // Logic Input Pin 7

#define LOGIC_PIN_8 14      // Logic Input Pin 8
#define LOGIC_PIN_9 15      // Logic Input Pin 9
#define LOGIC_PIN_10 16      // Logic Input Pin 10
#define LOGIC_PIN_11 17      // Logic Input Pin 11
#define LOGIC_PIN_12 20     // Logic Input Pin 12
#define LOGIC_PIN_13 21     // Logic Input Pin 13
#define LOGIC_PIN_14 22     // Logic Input Pin 14
#define LOGIC_PIN_15 26     // Logic Input Pin 15

uint8_t LogicGpioPins[16] = {
    LOGIC_PIN_0,
    LOGIC_PIN_1,
    LOGIC_PIN_2,
    LOGIC_PIN_3,
    LOGIC_PIN_4,
    LOGIC_PIN_5,
    LOGIC_PIN_6,
    LOGIC_PIN_7,
    LOGIC_PIN_8,
    LOGIC_PIN_9,
    LOGIC_PIN_10,
    LOGIC_PIN_11,
    LOGIC_PIN_12,
    LOGIC_PIN_13,
    LOGIC_PIN_14,
    LOGIC_PIN_15    
};

ST7735_TFT tft_display;

// Cache for previous logic states to avoid unnecessary display updates
uint16_t prev_logic_state = 0xFFFF; // Initialize to invalid state to force initial update

// Power management variables
volatile bool power_button_pressed = false;
uint32_t power_button_press_time = 0;
const uint32_t POWER_OFF_HOLD_TIME = 2000; // Hold power button for 2 seconds to shut down

// Battery monitoring variables
float battery_voltage = 0.0f;
uint32_t last_battery_check = 0;
uint32_t last_battery_display_update = 0;
const uint32_t BATTERY_CHECK_INTERVAL = 100; // Check battery every 1/10 seconds
const uint32_t BATTERY_DISPLAY_UPDATE_INTERVAL = 1000; // Update display every 1 second
const float BATTERY_LOW_THRESHOLD = 3.7f;     // Low battery warning at 3.7V
const float BATTERY_CRITICAL_THRESHOLD = 3.5f; // Critical battery at 3.5V
const float ADC_CONVERSION_FACTOR = 3.3f / (1 << 12); // 3.3V reference, 12-bit ADC
const float VOLTAGE_DIVIDER_FACTOR = 2.0f;    // Adjust based on your voltage divider

// Moving average for battery voltage (50 measurements)
const int BATTERY_SAMPLES = 50;
float battery_readings[BATTERY_SAMPLES];
int battery_sample_index = 0;
bool battery_samples_filled = false;
float battery_voltage_average = 0.0f;

void PowerButtonCallback(uint gpio, uint32_t events)
{
    if (gpio == POWER_BUTTON_PIN && (events & GPIO_IRQ_EDGE_FALL)) {
        power_button_pressed = true;
        power_button_press_time = to_ms_since_boot(get_absolute_time());
    }
}

void InitPowerManagement()
{
    // Initialize power control pin - keep power on (HIGH for PNP transistor)
    gpio_init(SYSTEM_POWER_PIN);
    gpio_set_dir(SYSTEM_POWER_PIN, GPIO_OUT);
    gpio_put(SYSTEM_POWER_PIN, 1); // HIGH = PNP conducts = MOSFET conducts = power on
    
    // Initialize power button pin with pull-up
    gpio_init(POWER_BUTTON_PIN);
    gpio_set_dir(POWER_BUTTON_PIN, GPIO_IN);
    gpio_pull_up(POWER_BUTTON_PIN);
    
    // Setup interrupt for power button
    gpio_set_irq_enabled_with_callback(POWER_BUTTON_PIN, GPIO_IRQ_EDGE_FALL, true, &PowerButtonCallback);
}

bool CheckPowerButton()
{
    if (power_button_pressed) {
        if (!gpio_get(POWER_BUTTON_PIN)) { // Button still pressed
            uint32_t current_time = to_ms_since_boot(get_absolute_time());
            if (current_time - power_button_press_time >= POWER_OFF_HOLD_TIME) {
                return true; // Time to power off
            }
        } else {
            // Button released before timeout
            power_button_pressed = false;
        }
    }
    return false;
}

void InitBatteryMonitoring()
{
    // Initialize ADC for battery monitoring
    adc_init();
    adc_gpio_init(BATTERY_ADC_PIN);
    adc_select_input(BATTERY_ADC_CHANNEL);
}

float ReadBatteryVoltage()
{
    adc_select_input(BATTERY_ADC_CHANNEL);
    uint16_t adc_raw = adc_read();
    float voltage = adc_raw * ADC_CONVERSION_FACTOR * VOLTAGE_DIVIDER_FACTOR;
    return voltage;
}

float UpdateBatteryMovingAverage(float new_reading)
{
    // Add new reading to circular buffer
    battery_readings[battery_sample_index] = new_reading;
    battery_sample_index = (battery_sample_index + 1) % BATTERY_SAMPLES;
    
    // Check if we've filled the buffer at least once
    if (!battery_samples_filled && battery_sample_index == 0) {
        battery_samples_filled = true;
    }
    
    // Calculate average
    float sum = 0.0f;
    int count = battery_samples_filled ? BATTERY_SAMPLES : battery_sample_index;
    
    for (int i = 0; i < count; i++) {
        sum += battery_readings[i];
    }
    
    return count > 0 ? sum / count : new_reading;
}

void DisplayBatteryStatus()
{
    // Display battery voltage in top right corner
    tft_display.setCursor(0, 115);
    tft_display.setTextColor(ST7735_TFT::C_WHITE, ST7735_TFT::C_BLACK);
    
    // Choose color based on battery level (using averaged voltage)
    uint16_t voltage_color = ST7735_TFT::C_GREEN;
    if (battery_voltage_average < BATTERY_CRITICAL_THRESHOLD) {
        voltage_color = ST7735_TFT::C_RED;
    } else if (battery_voltage_average < BATTERY_LOW_THRESHOLD) {
        voltage_color = ST7735_TFT::C_YELLOW;
    }
    
    tft_display.setTextColor(voltage_color, ST7735_TFT::C_BLACK);
    char voltage_str[16];
    snprintf(voltage_str, sizeof(voltage_str), "BATTERY: %.2fV", battery_voltage_average);
    tft_display.print(voltage_str);
}

void UpdateAndDisplayBattery()
{
    uint32_t current_time = to_ms_since_boot(get_absolute_time());
    
    // Update battery voltage measurement with moving average
    if (current_time - last_battery_check >= BATTERY_CHECK_INTERVAL) {
        float raw_voltage = ReadBatteryVoltage();
        battery_voltage_average = UpdateBatteryMovingAverage(raw_voltage);
        battery_voltage = battery_voltage_average; // Keep for compatibility
        last_battery_check = current_time;
    }
    
    // Update battery display
    if (current_time - last_battery_display_update >= BATTERY_DISPLAY_UPDATE_INTERVAL) {
        DisplayBatteryStatus();
        last_battery_display_update = current_time;
    }
}

bool CheckBatteryCritical()
{
    return (battery_voltage_average > 0.0f && battery_voltage_average < BATTERY_CRITICAL_THRESHOLD);
}

void PowerOff()
{
    // Display shutdown message
    tft_display.fillScreen(ST7735_TFT::C_BLACK);
    tft_display.setCursor(30, 60);
    tft_display.setTextColor(ST7735_TFT::C_WHITE, ST7735_TFT::C_BLACK);
    tft_display.print("POWER OFF ...!");
    sleep_ms(1000);
    
    // Turn off power control pin (LOW = PNP blocks = MOSFET blocks = power off)
    gpio_put(SYSTEM_POWER_PIN, 0);
    
    // If we get here, hardware shutdown failed - go to infinite loop
    while(true) {
        sleep_ms(1000);
    }
}

void InitLogicPinsAsInput()
{
    for(int i=0; i<16; i++)  // Initialize all 16 pins at once
    {
        gpio_init(LogicGpioPins[i]);
        gpio_set_dir(LogicGpioPins[i], GPIO_IN);
        gpio_set_pulls(LogicGpioPins[i], false, false);
        //gpio_pull_down(LogicGpioPins[i]);
    }
}

// Fast GPIO bulk read function - reads all GPIO states in one operation
inline uint16_t ReadAllLogicPins()
{
    uint16_t result = 0;
    uint32_t gpio_state = gpio_get_all();
    
    // Extract only the bits we need and pack them into 16-bit result
    for(int i = 0; i < 16; i++) {
        if(gpio_state & (1U << LogicGpioPins[i])) {
            result |= (1U << i);
        }
    }
    return result;
}

// Fast display update - only updates changed logic indicators
inline void UpdateLogicDisplay(uint16_t current_state, uint16_t prev_state)
{
    uint16_t changed_bits = current_state ^ prev_state;
    
    // Only update pins that have changed state
    for(int i = 0; i < 16; i++) {
        if(changed_bits & (1U << i)) {
            int row = (i < 8) ? 0 : 1;
            int col = i % 8;
            int x_pos = 7 + col * 19;
            int y_pos = 37 + row * 50;
            
            uint16_t color = (current_state & (1U << i)) ? ST7735_TFT::C_GREEN : ST7735_TFT::C_BLACK;
            tft_display.fillRect(x_pos, y_pos, 13, 13, color);
        }
    }
}

void DrawDisplayMask()
{
    tft_display.setCursor(0, 0);
    tft_display.print("- Pico Logiktester -");
    
    // Initialize battery voltage with first reading and moving average
    float initial_voltage = ReadBatteryVoltage();
    battery_voltage_average = UpdateBatteryMovingAverage(initial_voltage);
    DisplayBatteryStatus();

    int x_start = 5;
    int y_start = 25;

    tft_display.setTextColor(ST7735_TFT::C_WHITE, ST7735_TFT::C_BLACK);

    for(int i=0; i<8; i++)
    {
        // Draw logic input box 0-7
        tft_display.setCursor(x_start + i * 19 + 4, y_start);
        tft_display.print(i);
        tft_display.drawRectWH(x_start + i * 19, y_start + 10, 17, 17, ST7735_TFT::C_WHITE);
        
        // Draw logic input box 8-15
        tft_display.setCursor(x_start + i * 19 + 4, y_start + 50);
        tft_display.print(i+8, 16);
        tft_display.drawRectWH(x_start + i * 19, y_start + 10 + 50, 17, 17, ST7735_TFT::C_WHITE);
    }
}

int main()
{
    stdio_init_all();

    // onboard LED for debugging
    const uint LED_PIN = 25;
    gpio_init(LED_PIN);
    gpio_set_dir(LED_PIN, GPIO_OUT);
    gpio_put(LED_PIN, 1); // Turn on LED to indicate startup
    
    // Initialize power management first
    InitPowerManagement();
    
    // Initialize battery monitoring
    InitBatteryMonitoring();
    
    // Initialize display with faster SPI speed
    tft_display.TFTInitSPIType(16000, spi0); // Increased from 8000 to 16MHz for faster display updates
    tft_display.setupGPIO(TFT_RST_PIN, TFT_DC_PIN, TFT_CS_PIN, TFT_SCLK_PIN, TFT_SDIN_PIN);
    tft_display.TFTInitPCBType(ST7735_TFT::TFT_ST7735S_Black); // Initialize for BLACK Tab PCB
    tft_display.TFTInitScreenSize(0, 0, TFT_WIDTH, TFT_HEIGHT);
    tft_display.setRotation(displaylib_16_graphics::Degrees_90);
    tft_display.fillScreen(ST7735_TFT::C_BLACK);

    InitLogicPinsAsInput(); // Initialize all logic pins
    DrawDisplayMask();

    uint16_t current_logic_state = ReadAllLogicPins();
    prev_logic_state = current_logic_state;

    // It is important to do an initial display update
    UpdateLogicDisplay(current_logic_state, ~prev_logic_state);

    // Main loop with optimized performance
    while (true)
    {
        // Check for power button long press
        if (CheckPowerButton()) {
            PowerOff(); // This should not return
        }
        
        // Update battery voltage and display periodically (independent of logic changes)
        UpdateAndDisplayBattery();
        
        // Check for critical battery level
        if (CheckBatteryCritical()) {
            tft_display.fillScreen(ST7735_TFT::C_BLACK);
            tft_display.setCursor(40, 60);
            tft_display.setTextColor(ST7735_TFT::C_RED, ST7735_TFT::C_BLACK);
            tft_display.print("LOW BATTERY!");
            sleep_ms(2000);
            PowerOff();
        }
        
        // Fast bulk read of all GPIO pins
        current_logic_state = ReadAllLogicPins();
        
        // Only update logic display if logic state changed
        if(current_logic_state != prev_logic_state) {
            UpdateLogicDisplay(current_logic_state, prev_logic_state);
            prev_logic_state = current_logic_state;
        }
        
        // Reduced sleep for faster response time (5ms instead of 20ms)
        sleep_ms(5);
    }

    return 0;
}

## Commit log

2026-01-15 hardware: start
    [pico_logictester.kicad_pcb, pico_logictester.kicad_sch]
2026-01-15 hardware: Eingänge beschaltet, und tft angeschlossen
    [pico_logictester.kicad_sch]
2026-01-17 hardware: Alle baugruppen im schaltplan hinzugefügt.
    [pico_logictester.kicad_sch]
2026-01-17 firmware: spannungswerte für battery überwachung auf 3.7 für Low und 3.5 zum Abschalten gesetzt.
2026-01-20 hardware: Schaltplan fertig gestellt und Footprints zugeordnet
    [pico_logictester.kicad_sch]
2026-01-22 Autorouting im Livestream. noch 6 offene Verbindungen!
    [pico_logictester.dsn, pico_logictester.kicad_pcb, pico_logictester.kicad_sch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]
2026-01-24 hardware: ERC Error behoben
    [pico_logictester.kicad_sch]
2026-01-24 hardware: new pcb layout
    [pico_logictester.dsn, pico_logictester.kicad_pcb, pico_logictester.kicad_sch]
2026-01-24 remove files
    [pico_logictester.dsn, pico_logictester.kicad_pcb, pico_logictester.kicad_sch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]
2026-01-24 hardware: bauckup
    [pico_logictester.dsn, pico_logictester.kicad_pcb]
2026-01-24 hardware: pcb_1.0 fertig gestellt und Gerberfiles erstellt.
    [pico_logictester.dsn, pico_logictester.kicad_pcb, pico_logictester.kicad_sch]
2026-01-25 hardware: Interaktive BOM hinzugefügt (mit PlugIn: Interactive Html Bom)
    [pico_logictester.kicad_pcb]
2026-01-25 doc: Schaltplan v1.0 als PDF hinzugefügt
    [pico_logictester.kicad_sch]
2026-02-21 On Board LED wird beim Start des Pico eingeschaltet. Als Indikator das der Pico und die Firmware läuft.
2026-02-21 Squashed commit of the following:
    commit bb0bbc1d573e0b7ef0f2029c41a12eb1b7a3b53d
    Author: Thorsten Kattanek <thorsten.kattanek@gmx.de>
    Date: Sat Feb 21 18:10:56 2026 +0100
    Update README.md
    commit 1b0319603f573a80e1201760700dad0fea377821
    Author: Thorsten Kattanek <thorsten.kattanek@gmx.de>
    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
2026-02-21 Neues FreeCad Projekt für das Case
    [pico_logictester_case.FCStd]
2026-02-21 Angefangen die obere Hälfte des Gehäuses zu erstellen.
    [pico_logictester_case.FCStd]
2026-02-28 Angefangen die unterer Gehäusehälfte zu erstellen.
    [pico_logictester_case.FCStd]
2026-03-03 Hinweis im Schaltplan hinzugefügt. D2 kann entfallen, und wird nicht benötigt.
    [pico_logictester.kicad_sch]
2026-03-07 Gehäuse endlich fertig! Hoffentlich :)
    [pico_logictester_case.FCStd]
2026-03-12 4x Fase noch dran gemacht
    [pico_logictester_case.FCStd]
2026-03-12 Case: 4x Durchmesser 2,5 auf 2,0 geändert. Halterung für TFT Display
    [pico_logictester_case.FCStd]
2026-03-21 Gehäuse nochmal ein wenig angepasst. Verschiedene Durchmesser geändert + Abstandshalter seitlich mit Gehäuse Verbunden, da sie sonst leicht abbrechen können.
    [pico_logictester_case-bottom_case.step, pico_logictester_case-top_case.step, pico_logictester_case.FCStd]
